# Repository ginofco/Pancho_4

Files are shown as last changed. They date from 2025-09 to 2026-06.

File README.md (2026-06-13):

# Projeto Pancho_4






## 📋 Descrição do Projeto

Protótipo de robô controlado remotamente via rádio utilizando módulos transceptores NRF24L01, desenvolvido para participação em eventos de cultura maker, por exemplo Arduino Day. O projeto inclui um chassis com ponte H e dois motores DC com rodas para movimento, com possibilidade de expansão para um braço robótico.

## ✨ Funcionalidades

- Controle remoto via rádio com módulos NRF24L01
- Chassis personalizado impresso em 3D
- Controle de motores DC com ponte H
- Design modular para futuras expansões (braço robótico)

## 🛠️ Tecnologias e Componentes

- **Microcontroladores:** Arduino Uno R3
- **Comunicação:** Módulos NRF24L01
- **Motores:** 2x Motores DC com caixa de redução, servomotores
- **Driver de Motor:** Ponte H L298N ou similar
- **Power:** Bateria LiPo 7.4V ou baterias de litio
- **Produção:** Impressora 3D Ender-3 Pro
- **Design:** FreeCAD, TinkerCAD

## 📁 Estrutura do Projeto

```
Arduino_Day_2026_Robo/
├── 1_Documentacao/          # Documentação, datasheets e referências
├── 2_Design/                # Arquivos de design 3D (FreeCAD e STLs)
├── 3_Firmware/              # Códigos Arduino para todos os dispositivos
├── 4_Hardware/              # Esquemas elétricos e designs de PCB
└── 5_TestesEvidencias/      # Registros de testes, fotos e vídeos
```

## 🚀 Como Usar

### Pré-requisitos

- IDE Arduino
- Biblioteca RF24 (para comunicação NRF24L01)
- FreeCAD (para visualização e edição de modelos)

### Instalação

1. Clone este repositório:
```bash
git clone https://github.com/[seu-usuario]/ArduinoDay2026-RoboRadio.git
```

2. Instale as bibliotecas necessárias na IDE Arduino:
   - RF24 by TMRh20
   - Outras bibliotecas listadas em `3_Firmware/Bibliotecas/`

3. Abra o sketch desejado na pasta `3_Firmware/`

### Upload para o Arduino

1. Conecte o Arduino ao computador
2. Selecione a placa e porta corretas na IDE Arduino
3. Compile e faça upload do código

## 🎮 Como Controlar

[Descreva aqui como operar o robô quando estiver pronto]

## 📸 Fotos do Projeto

*(Adicione fotos do progresso aqui)*

## 📝 Registro de Desenvolvimento

- **Agosto 2025**: Início do projeto, definição de escopo e estrutura
- **Setembro 2025**: Desenvolvimento do chassis e comunicação básica
- **[Adicione novas etapas conforme o progresso]**

## 👥 Autor

- **Gino** - Maker e entusiasta de robótica - [Comunidade Maker RJ]

## 🙌 Agradecimentos

- Comunidade Maker do Rio de Janeiro
- Fabricantes dos componentes e bibliotecas utilizadas
- Organizadores do Arduino Day 2026
- FabLab do PoloMaker (Rio de Janeiro)

## 📄 Licença

Este projeto está sob a licença MIT. Veja o arquivo [LICENSE](LICENSE) para detalhes.

---

**Nota:** Este projeto está em desenvolvimento. Atualizações regulares serão feitas conforme o progresso.

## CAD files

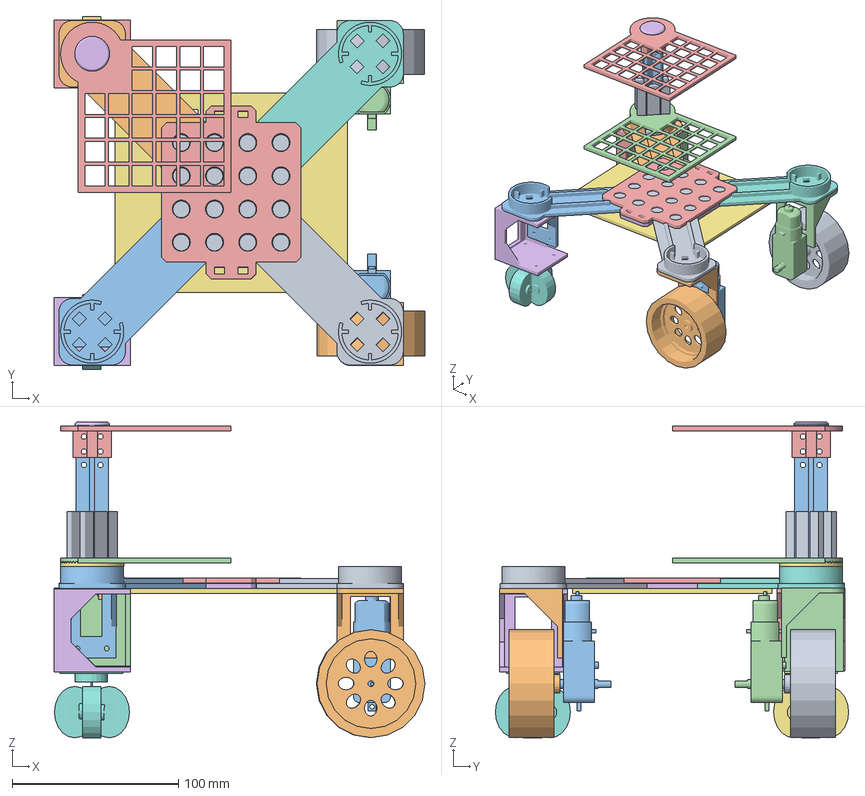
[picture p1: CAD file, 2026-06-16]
2_Design/21_FreeCAD/P4.FCStd
223.3 x 212.7 x 190.0 mm
Core1
Radial_Arm
P3_Suporte_Motor001 (Solid)
Suporte_Motor
Suporte_RodaBoba
Core2
Suporte_Coluna_1
Suporte_Coluna_2
Suporte_Coluna_3
Suporte_Coluna_4
Coluna
Prateleira
Elo_de_Coluna
Topo_Coluna
Javier_aluno
P4_RadialArm_TKCAD_1
P4_RadialArm_TKCAD_2
P4_SuporteMotor_TKCAD
P4_RadialArm_TKCAD_3
P3_Suporte_RodaBoba_TKCAD
P4_Core2_TKCAD
P4_SuporteRodaBoba_TKCAD
P3_RodaBoba_TKCAD_1
P3_RodaBoba_TKCAD_2
P3_RodaGrande_TKCAD_1
P3_RodaGrande_TKCAD_2
P3_Motor_TKCAD_1
P3_Motor_TKCAD_2
P4-Prateleira

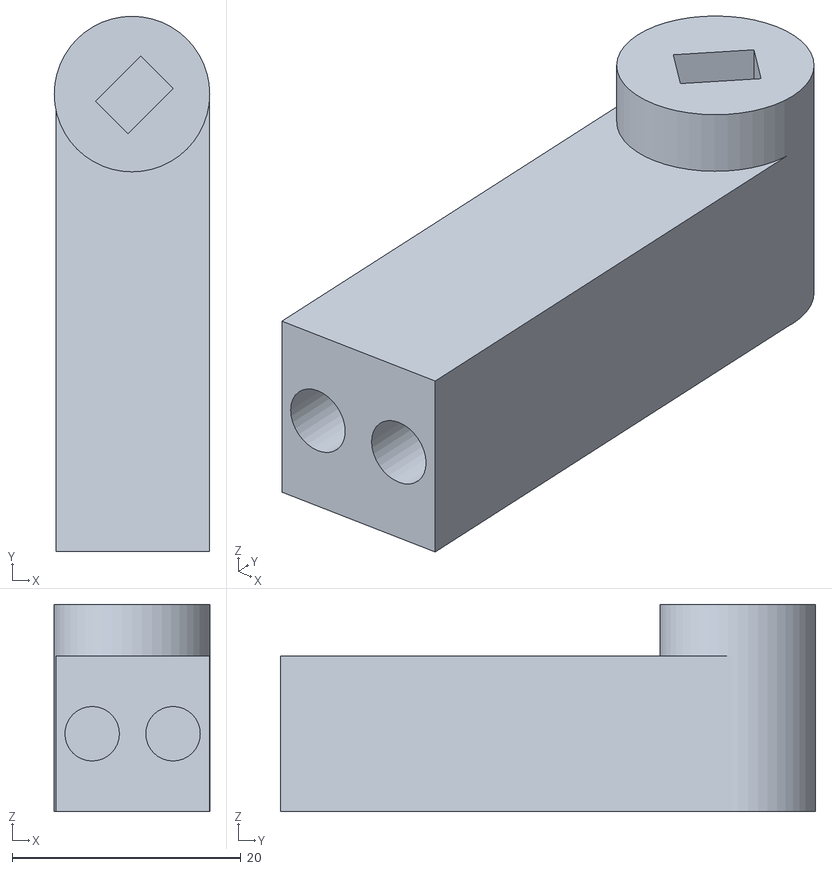
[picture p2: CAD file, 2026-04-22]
2_Design/22_TinkerCAD/P4_Braco-v2.stl
13.6 x 46.8 x 18.1

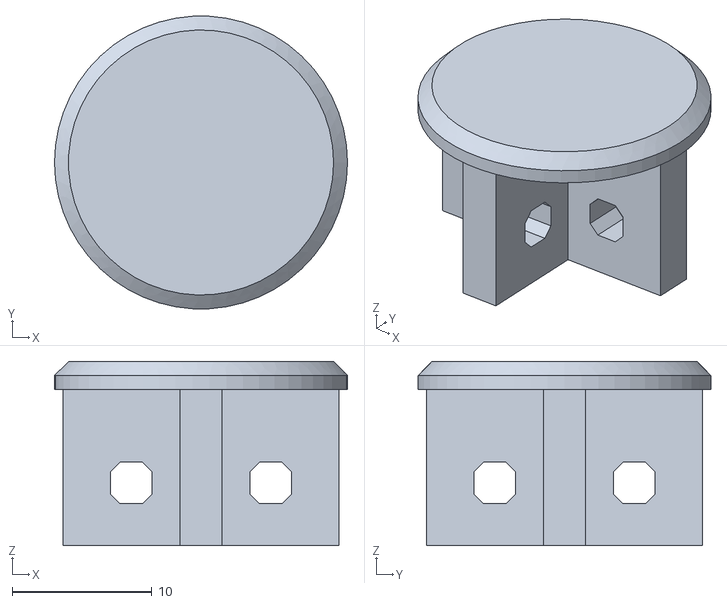
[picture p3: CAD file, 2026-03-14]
2_Design/21_FreeCAD/P4-Topo_Coluna.stl
21.0 x 21.0 x 13.2

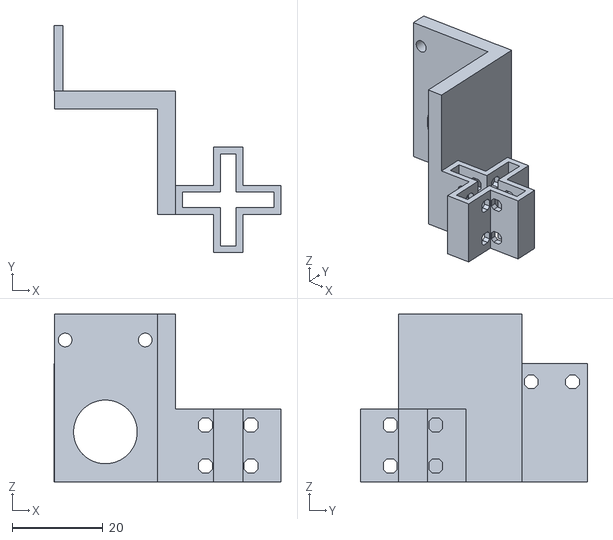
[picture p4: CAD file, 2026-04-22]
2_Design/22_TinkerCAD/P4_SuporteBraco-v2.stl
49.9 x 50.0 x 36.9

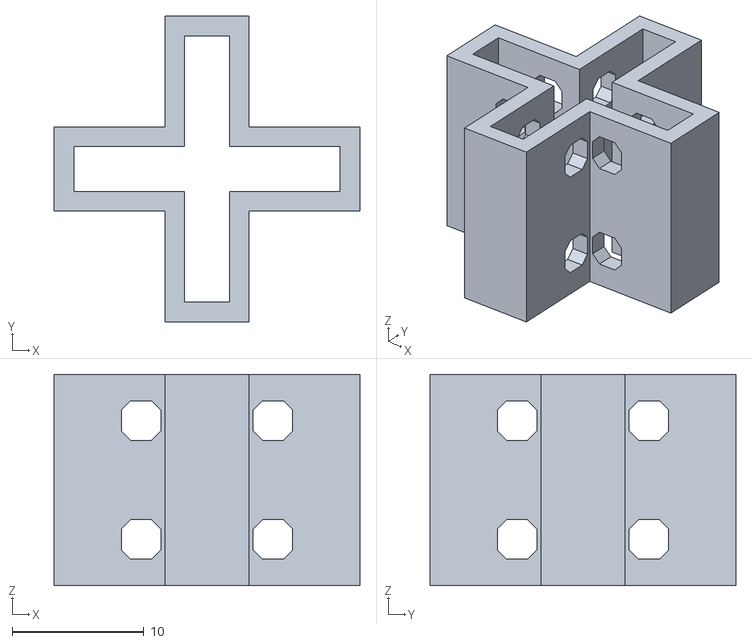
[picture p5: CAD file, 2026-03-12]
2_Design/21_FreeCAD/P4-Elo_de_Coluna.stl
23.2 x 23.2 x 16.0

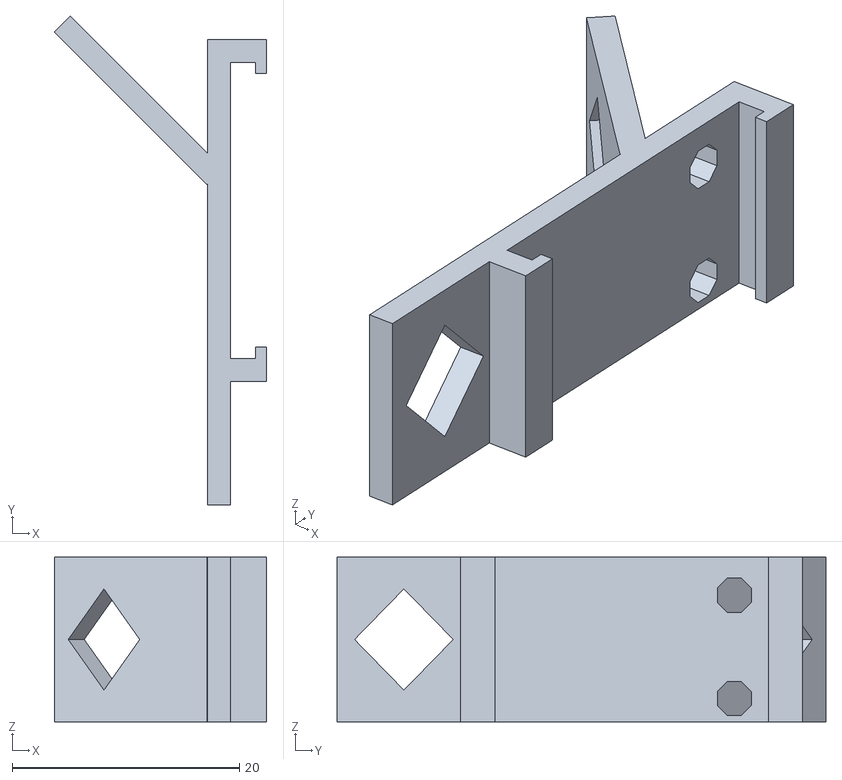
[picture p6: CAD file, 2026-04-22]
2_Design/22_TinkerCAD/P4_SuporteStopBraco-v2.stl
18.7 x 43.1 x 14.5

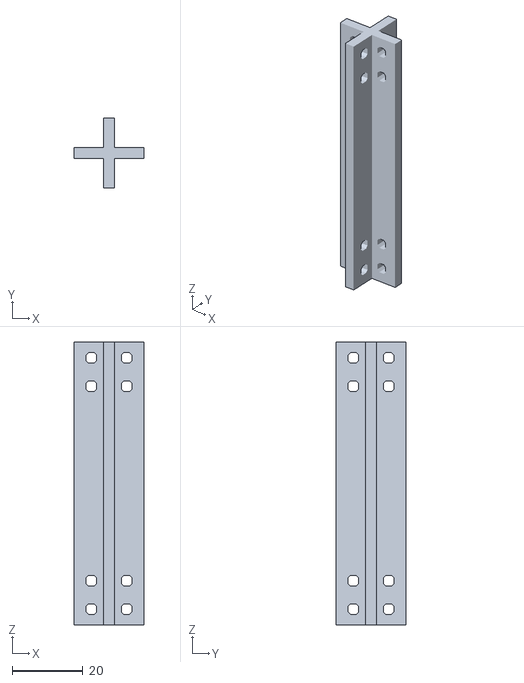
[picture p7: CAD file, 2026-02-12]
2_Design/21_FreeCAD/P4-Coluna.stl
19.8 x 19.8 x 80.0

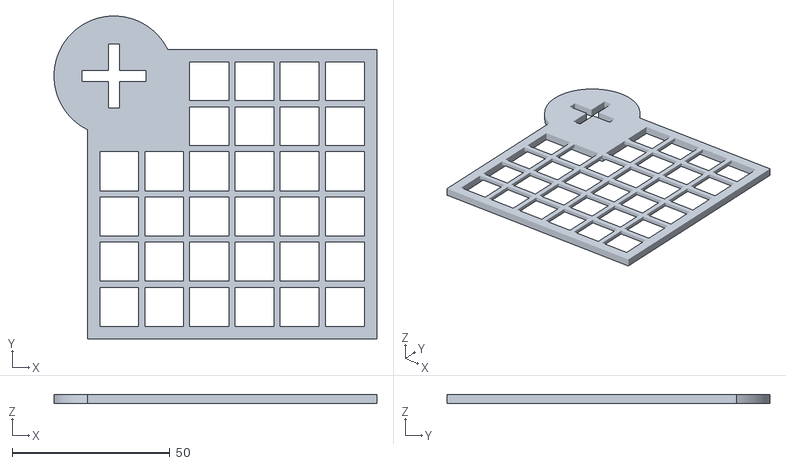
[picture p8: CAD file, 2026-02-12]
2_Design/21_FreeCAD/P4-Prateleira.stl
102.4 x 102.4 x 3.00

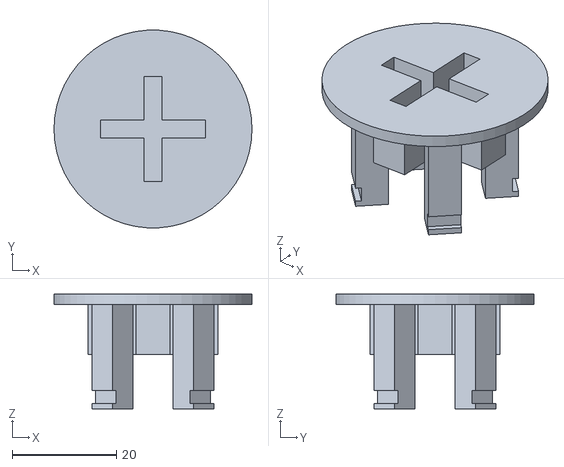
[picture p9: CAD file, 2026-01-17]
2_Design/21_FreeCAD/P4-Suporte_Coluna_4.stl
38.0 x 37.9 x 22.0

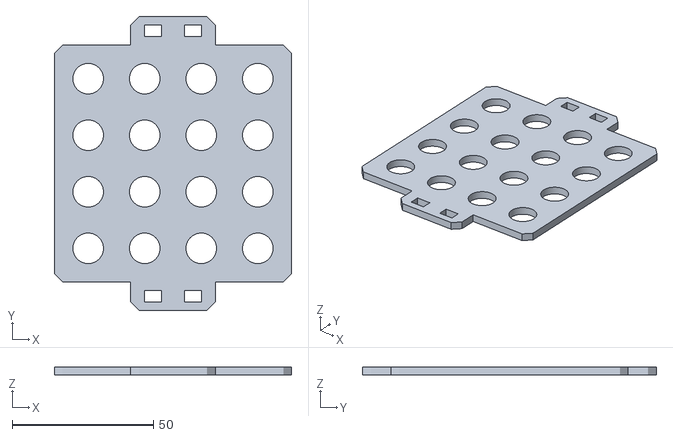
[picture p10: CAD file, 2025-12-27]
2_Design/21_FreeCAD/P4-Core2.stl
84.0 x 104.0 x 3.00

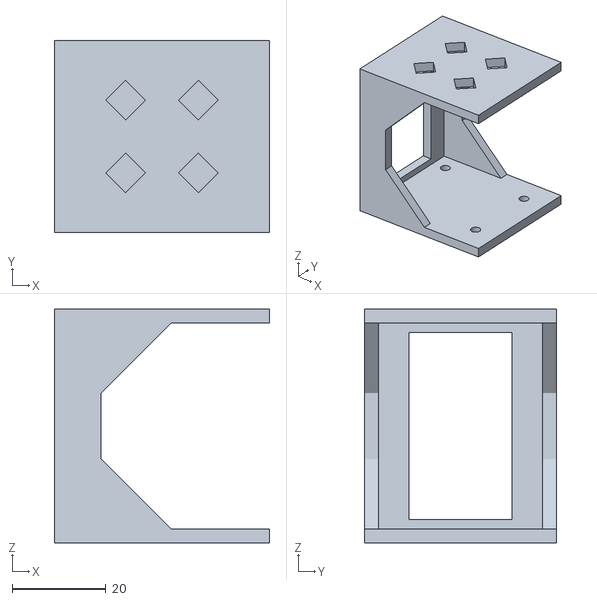
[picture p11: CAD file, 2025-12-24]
2_Design/21_FreeCAD/P4-Suporte_RodaBoba.stl
46.0 x 41.0 x 50.0

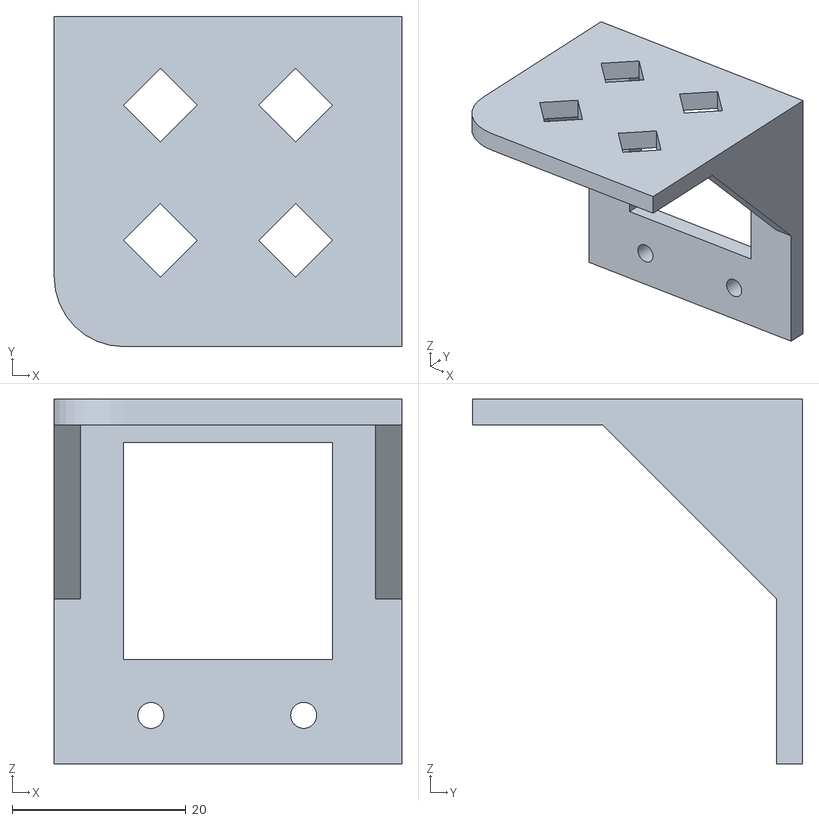
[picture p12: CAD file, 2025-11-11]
2_Design/21_FreeCAD/P4-Suporte_Motor.stl
40.0 x 38.0 x 42.0

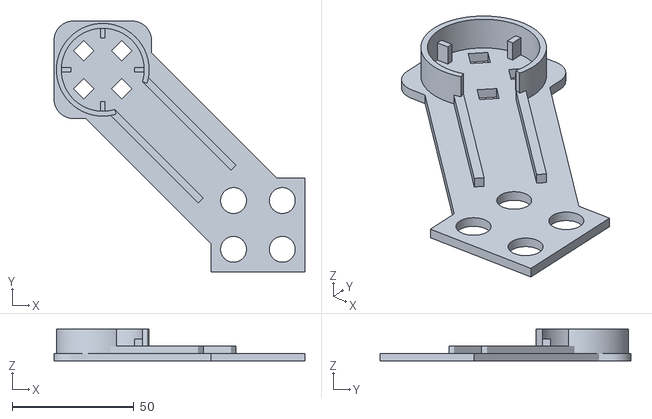
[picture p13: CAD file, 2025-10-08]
2_Design/21_FreeCAD/P4-Radial_Arm.stl
102.9 x 102.9 x 13.0

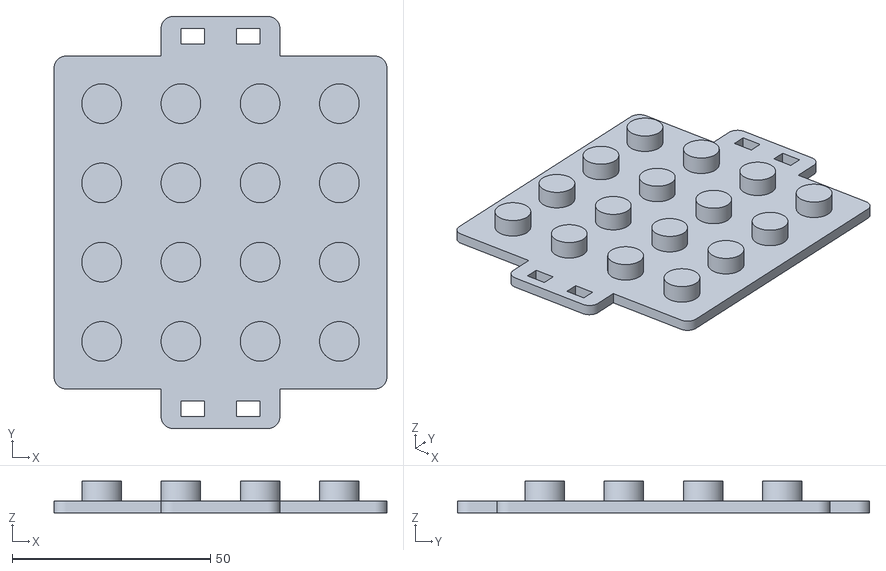
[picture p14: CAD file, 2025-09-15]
2_Design/21_FreeCAD/P4-Core1.stl
84.0 x 104.0 x 8.00

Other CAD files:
2_Design/22_TinkerCAD/P4_Braco.stl
2_Design/22_TinkerCAD/P4_SuporteStopBraco.stl
2_Design/22_TinkerCAD/P4_SuporteBraco.stl

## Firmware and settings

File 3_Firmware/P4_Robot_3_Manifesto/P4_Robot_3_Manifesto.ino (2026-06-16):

// Pancho 4: robot radiocontrolado
// Codigo do Robot - Módulo "Manifesto"
// I2C Slave
// https://www.arduino.cc/en/Tutorial/Tone

#define SLAVE_ADDRESS 0x08
#include <Wire.h>
#include "pitches.h"
#define LEDBLUE 8
#define dirFrente 5
#define dirTras 3
#define esqFrente 9
#define esqTras 6

int volante;
int marcha_frente;
int marcha_tras;
int velocidade=200;
int Motor_L;
int Motor_R;

// notes in the melody:
int melody[] = {
  NOTE_C4, NOTE_G3, NOTE_G3, NOTE_A3, NOTE_G3, 0, NOTE_B3, NOTE_C4
};
// note durations: 4 = quarter note, 8 = eighth note, etc.:
int noteDurations[] = {
  4, 8, 8, 4, 4, 4, 4, 4
};

struct DataPackage {
  int buzina;
  int Motor_L_val;
  int Motor_R_val;
} receivedData;
const int PACKAGE_SIZE = sizeof(DataPackage);

void setup() {
  Serial.begin(57600);
  Serial.println("Pancho 4 - Manifesto: ativado.");

  Wire.begin(SLAVE_ADDRESS);    // join i2c bus with address #8
  //Wire.onReceive(receiveEvent);
  Wire.onReceive(receiveData);
  
  pinMode(esqFrente, OUTPUT);
  pinMode(esqTras, OUTPUT);
  pinMode(dirTras, OUTPUT);
  pinMode(dirFrente, OUTPUT);
  pinMode(LEDBLUE, OUTPUT);
}

byte c=0;
//void receiveEvent(int howMany) {
//   c = Wire.read();
//}

// Função chamada quando dados são recebidos do mestre
void receiveData(int byteCount) {
  if(byteCount == PACKAGE_SIZE) {
    uint8_t *dataPtr = (uint8_t*)&receivedData;
    for(int i = 0; i < PACKAGE_SIZE && Wire.available(); i++) {
      dataPtr[i] = Wire.read();
    }
    // Processar dados recebidos
    processReceivedData();
  } else {
    Serial.print("Tamanho inesperado: ");
    Serial.println(byteCount);
  }
}

void processReceivedData() {
  //Serial.println("\n=== Dados Recebidos ===");
  Serial.print("Modulo Manifesto. Mensagem: velocidade: ");
  Serial.print(receivedData.Motor_L_val);
  Serial.print(" - controle_motores: ");
  Serial.print(receivedData.Motor_R_val);
  Serial.print(" - buzina: ");
  Serial.println(receivedData.buzina);
}


int  velocidade_L;
int  velocidade_R;
void loop() {
  
   Motor_L = receivedData.Motor_L_val;
   Motor_R = receivedData.Motor_R_val;

   if (( Motor_L == 127 ) && ( Motor_R == 127 )) apaga_todos();

   if (( Motor_L <= 127 ) && ( Motor_R <= 127 )) {
     velocidade_L = 200 * ( 127 - Motor_L ) / 127;
     velocidade_R = 200 * ( 127 - Motor_R ) / 127;
     move_p_frente(velocidade_L, velocidade_R);
   }
   if (( Motor_L > 127 ) && ( Motor_R > 127 )) {
     velocidade_L = 200 * ( Motor_L - 127 ) / 127;
     velocidade_R = 200 * ( Motor_R - 127 ) / 127;
     move_p_tras(velocidade_L, velocidade_R);
   }

   /*
   switch(c) {
    case 0:
      apaga_todos();
      break;
    case 1:
      move_p_frente(velocidade);
      break;
    case 2:
      move_p_esquerda_frente(velocidade);
      break;
    case 3:
      move_p_direita_frente(velocidade);
      break;
    case 4:
      move_p_tras(velocidade);
      break;
    case 5:
      move_p_esquerda_tras(velocidade);
      break;
    case 6:
      move_p_direita_tras(velocidade);
      break;
    case 8:
      //play_song();
      acende_blue();
      break;
    case 9:
      //play_song();
      apaga_blue();
      break;
  } 
  */
  // delay(500);
}

void play_song() {
  for (int thisNote = 0; thisNote < 8; thisNote++) {
    // to calculate the note duration, take one second divided by the note type.
    //e.g. quarter note = 1000 / 4, eighth note = 1000/8, etc.
    int noteDuration = 1000 / noteDurations[thisNote];
    tone(8, melody[thisNote], noteDuration);
    // to distinguish the notes, set a minimum time between them.
    // the note's duration + 30% seems to work well:
    int pauseBetweenNotes = noteDuration * 1.30;
    delay(pauseBetweenNotes);
    // stop the tone playing:
    noTone(8);
  }
}

void move_p_frente(int velocidade_L, int velocidade_R) {
  acende_0(velocidade_L);
  apaga_1();
  acende_2(velocidade_R);
  apaga_3();
}
void move_p_tras(int velocidade_L, int velocidade_R) {
  apaga_0();
  acende_1(velocidade_L);  
  apaga_2();
  acende_3(velocidade_L);
}
void move_p_esquerda_frente(int velocidade) {
  acende_0(velocidade);
  apaga_1();
  apaga_2();
  apaga_3();
}
void move_p_direita_frente(int velocidade) {
  apaga_0();
  apaga_1();
  acende_2(velocidade);
  apaga_3();
}
void move_p_esquerda_tras(int velocidade) {
  apaga_0();
  apaga_1();
  apaga_2();
  acende_3(velocidade);
}
void move_p_direita_tras(int velocidade) {
  apaga_0();
  acende_1(velocidade);
  apaga_2();
  apaga_3();
}
void apaga_todos() {
  apaga_0();
  apaga_1();  
  apaga_2();
  apaga_3();
}

void acende_0(int velocidade) {
  analogWrite(esqFrente, velocidade);
}
void acende_1(int velocidade) {
  analogWrite(esqTras, velocidade);
}
void acende_2(int velocidade) {
  analogWrite(dirTras, velocidade);
}
void acende_3(int velocidade) {
  analogWrite(dirFrente, velocidade);
}

void apaga_0() {
  digitalWrite(esqFrente, LOW);
}
void apaga_1() {
  digitalWrite(esqTras, LOW);
}
void apaga_2() {
  digitalWrite(dirTras, LOW);
}
void apaga_3() {
  digitalWrite(dirFrente, LOW);
}

void acende_blue() {
  digitalWrite(LEDBLUE, HIGH);
}
void apaga_blue() {
  digitalWrite(LEDBLUE, LOW);
}

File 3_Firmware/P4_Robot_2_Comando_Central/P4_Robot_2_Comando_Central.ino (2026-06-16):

// Pancho 4: robot radiocontrolado
// Codigo do Robot - Módulo "Controle Central"
// I2C Master

#include <Wire.h>  // I2C
#define SLAVE_ADDRESS_7 0x07  // Comms_RRF
#define SLAVE_ADDRESS_8 0x08  // Manifesto

byte state = 0;

struct DataPackage {
  int buzina;
  int Motor_L_val;
  int Motor_R_val;
} dataToSend_Manifesto;
const int PACKAGE_SIZE = sizeof(DataPackage);

struct NewDataPackage {
  boolean ps2_PSB_SELECT;  // buttons pressed, released or changed state
  boolean ps2_PSB_START;
  boolean ps2_PSB_PAD_UP;
  boolean ps2_PSB_PAD_RIGHT;
  boolean ps2_PSB_PAD_DOWN;
  boolean ps2_PSB_PAD_LEFT;
  boolean ps2_PSB_L2;
  boolean ps2_PSB_R2;
  boolean ps2_PSB_L1;
  boolean ps2_PSB_R1;
  boolean ps2_PSB_GREEN;
  boolean ps2_PSB_RED;
  boolean ps2_PSB_BLUE;
  boolean ps2_PSB_PINK;
  byte    ps2_PSS_RX;  // "Sticks" values
  byte    ps2_PSS_RY;
  byte    ps2_PSS_LX;
  byte    ps2_PSS_LY;
} newReceivedData;

const int NEW_PACKAGE_SIZE = sizeof(NewDataPackage);

void setup() {
  Serial.begin(57600);
  Wire.begin(); // join i2c bus (address optional for master)
  
  iniciaEstrutura();
  
  Serial.println("Pancho 4 - Controle Central: ativado.");
  dataToSend_Manifesto.buzina = 0;
  dataToSend_Manifesto.Motor_L_val = 127;
  dataToSend_Manifesto.Motor_R_val = 127;
}

void loop() {
    //Serial.print("Master. Recebendo dados: ");   
    // Solicita dados do slave
    requestDataFromSlave();
    
    //displayData();
    
    dataToSend_Manifesto.buzina      = newReceivedData.ps2_PSB_BLUE;
    dataToSend_Manifesto.Motor_L_val = newReceivedData.ps2_PSS_RY;
    dataToSend_Manifesto.Motor_R_val = newReceivedData.ps2_PSS_LY;
  
    Serial.print("Master. Enviando dados: ");    
    Serial.print(" - buzina: ");
    Serial.print(dataToSend_Manifesto.buzina);
    Serial.print(" - Motor L: ");
    Serial.print(dataToSend_Manifesto.Motor_L_val);
    Serial.print(" - Motor R: ");
    Serial.print(dataToSend_Manifesto.Motor_R_val);
    Serial.println(" ");

    transmitData_Manifesto();

    //dataToSend_Manifesto.buzina++;
    //if (dataToSend_Manifesto.buzina>1) dataToSend_Manifesto.buzina=0;
    //dataToSend_Manifesto.controle_motores++;
    //if (dataToSend_Manifesto.controle_motores>9) dataToSend_Manifesto.controle_motores=0;

    // Aguarda um tempo antes da próxima leitura
    delay(50);
}

void requestDataFromSlave() {
  // Solicita o número de bytes igual ao tamanho da estrutura
  Wire.requestFrom(SLAVE_ADDRESS_7, sizeof(NewDataPackage));
  
  // Verifica se recebeu a quantidade correta de bytes
  uint8_t bytesReceived = 0;
  if(Wire.available() >= sizeof(NewDataPackage)) {
    
    // Lê os bytes diretamente para a estrutura
    for(uint8_t i = 0; i < sizeof(NewDataPackage); i++) {
      ((uint8_t*)&newReceivedData)[i] = Wire.read();
    }
    bytesReceived = sizeof(NewDataPackage);
    
    // Processa os dados recebidos
    //displayReceivedData();
    
  } else {
    Serial.print("Erro: Recebido apenas ");
    Serial.print(Wire.available());
    Serial.print(" de ");
    Serial.print(sizeof(NewDataPackage));
    Serial.println(" bytes esperados");
  }
}

void transmitData_Manifesto() {
  Wire.beginTransmission(SLAVE_ADDRESS_8);
  // Envia byte a byte da estrutura
  uint8_t *dataPtr = (uint8_t*)&dataToSend_Manifesto;
  for(size_t i = 0; i < PACKAGE_SIZE; i++) {
    Wire.write(dataPtr[i]);
  }
  byte error = Wire.endTransmission();
}

void iniciaEstrutura() {
  newReceivedData.ps2_PSB_SELECT    = false;
  newReceivedData.ps2_PSB_START     = false;
  newReceivedData.ps2_PSB_R1        = false;
  newReceivedData.ps2_PSB_R2        = false;
  newReceivedData.ps2_PSB_L1        = false;
  newReceivedData.ps2_PSB_L2        = false;
  newReceivedData.ps2_PSB_PAD_UP    = false;
  newReceivedData.ps2_PSB_PAD_RIGHT = false;
  newReceivedData.ps2_PSB_PAD_DOWN  = false;
  newReceivedData.ps2_PSB_PAD_LEFT  = false;
  newReceivedData.ps2_PSB_GREEN     = false;
  newReceivedData.ps2_PSB_RED       = false;
  newReceivedData.ps2_PSB_BLUE      = false;
  newReceivedData.ps2_PSB_PINK      = false;
  newReceivedData.ps2_PSS_RX        = 128;
  newReceivedData.ps2_PSS_RY        = 128;
  newReceivedData.ps2_PSS_LX        = 128;
  newReceivedData.ps2_PSS_LY        = 128;
}

void displayData() {
    Serial.print("P4_ModuloRRF. - Select: "); Serial.print(newReceivedData.ps2_PSB_SELECT);
    Serial.print(" - Start: ");             Serial.print(newReceivedData.ps2_PSB_START);
    Serial.print(" - R1: ");                Serial.print(newReceivedData.ps2_PSB_R1);
    Serial.print(" - R2: ");                Serial.print(newReceivedData.ps2_PSB_R2);
    Serial.print(" - L1: ");                Serial.print(newReceivedData.ps2_PSB_L1);
    Serial.print(" - L2: ");                Serial.print(newReceivedData.ps2_PSB_L2);
    Serial.print(" - PAD_UP: ");            Serial.print(newReceivedData.ps2_PSB_PAD_UP);
    Serial.print(" - PAD_RIGHT: ");         Serial.print(newReceivedData.ps2_PSB_PAD_RIGHT);
    Serial.print(" - PAD_DOWN: ");          Serial.print(newReceivedData.ps2_PSB_PAD_DOWN);
    Serial.print(" - PAD_LEFT: ");          Serial.print(newReceivedData.ps2_PSB_PAD_LEFT);
    Serial.print(" - GREEN: ");             Serial.print(newReceivedData.ps2_PSB_GREEN);
    Serial.print(" - RED: ");               Serial.print(newReceivedData.ps2_PSB_RED);
    Serial.print(" - BLUE: ");              Serial.print(newReceivedData.ps2_PSB_BLUE);
    Serial.print(" - PINK: ");              Serial.print(newReceivedData.ps2_PSB_PINK);
    Serial.print(" - RX: ");                Serial.print(newReceivedData.ps2_PSS_RX);
    Serial.print(" - RY: ");                Serial.print(newReceivedData.ps2_PSS_RY);
    Serial.print(" - LX: ");                Serial.print(newReceivedData.ps2_PSS_LX);
    Serial.print(" - LY: ");                Serial.print(newReceivedData.ps2_PSS_LY);
    Serial.println(" * ");
}

////////////////////////////////////////////////////////////////////////

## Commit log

2025-09-08 Create README.md
    Copiando o README.md para a raiz. Realizar o apagamento do arquivo copiado de ~/Documentacao
2025-09-15 Lançamento_da_Primeira_Peça
    Agregando o projeto FreeCAD do P4, já com primeira peça, em impressão
    [P4-Core1.stl, P4.FCStd]
2025-09-16 Iniciando a 2a parte (Radial_Arm)
    [P4.FCStd]
2025-09-20 Atualizacoes na peca Radial Arm
    [P4.FCStd]
2025-09-23 Mais uma atualizacao do Radial Arm
    [P4.FCStd]
2025-09-30 Nova atualizacao de 30-09-2025
    [P4.FCStd]
2025-10-08 Melhoria efetiva do Radial_Arm
    [P4-Radial_Arm.stl, P4.FCStd]
2025-10-11 Inclusao do Suporte_Motor de STL para Mesh, posicionamento
    [P4.FCStd]
2025-10-14 Atualização do SuporteMotor
    [P4.FCStd]
2025-10-18 Iniciando 4a peça: Suporte_coluna.
    [P4-Suporte_Motor.stl, P4.FCStd]
2025-10-22 Ajuste no suporte da coluna, inserindo borda semicircular.
    [P4.FCStd]
2025-11-04 Final do suporte de coluna.
    [P4-Suporte_Coluna.stl, P4.FCStd]
2025-11-11 Correções radicais no projeto CAD, mais teste com Arduino e PS2, mais cópias dos programas do P4 para pasta de GitHub.
    [P4-Suporte_Coluna.stl, P4-Suporte_Motor.stl, P4.FCStd]
2025-12-09 Testes e inserção de comandos I2C
2025-12-10 Adaptação do código do Console - Módulo PS2 - para receber estrutura de dados do controle PS2
2025-12-13 Teste bem sucedido de comunicação I2C entre Console-PS2 E Console-RRF
2025-12-16 Teste bem-sucedido de comunicação RF entre console (completo) e primeiro módulo do robô.
2025-12-16 Melhorias no modelo 3d
    [P4.FCStd]
2025-12-18 Refazendo parte do Suporte da Roda Boba
    [P4.FCStd]
2025-12-24 Suporte de roda boba adicionado.
    [P4-Suporte_RodaBoba.stl, P4-Suporte_RodaBoba_.stl, P4-Suporte_RodaBoba_1.stl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]
2025-12-27 Inclusão da parte P4-Core2
    [P4-Core2.stl, P4-Suporte_RodaBoba.stl, P4-Suporte_RodaBoba_.stl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]
2025-12-27 Agregação das partes, com inclusão de motores e de rodas.
    [P4.FCStd]
2025-12-29 Adicionado suporte para coluna
    [P4-Suporte_Coluna_1.stl, P4.FCStd]
2026-01-06 Testes em ideias para Suporte da Coluna.
    [P4.FCStd]
2026-01-07 Início da 3 tentativa para Suporte da Coluna (ou primeira coluna, direto)
    [P4.FCStd]
2026-01-10 Etapa de elaboração do suporte da coluna
    [P4.FCStd]
2026-01-14 Seguindo com a 4a tentativa para Suporte da Coluna.
    [P4.FCStd]
2026-01-17 Peça completada Suporte_Coluna_4.
    [P4-Suporte_Coluna_4.stl, P4.FCStd]
2026-01-25 Coluna com 16 furos.
    descrição
    [P4.FCStd]
2026-01-27 Iniciando Prateleira
    [P4.FCStd]
2026-02-03 Início da Plataforma
    [P4.FCStd]
2026-02-04 Vazando grade na Prateleira, com entrada para coluna
    [P4.FCStd]
2026-02-07 Escavando parte útil da Prateleira
    [P4.FCStd]
2026-02-12 Alterações na Coluna, visando melhor adaptar o conector entre colunas
    [P4-Coluna.stl, P4-Prateleira.stl, P4.FCStd]
2026-03-04 Criando o Elo_de_Coluna
    [P4.FCStd]
2026-03-10 Finalizado elo entre colunas.
    [P4-Suporte_Coluna_1.stl, P4.FCStd]
2026-03-12 Exportando o Elo de Coluna, exibindo o robô.
    [P4-Elo_de_Coluna.stl, P4.FCStd]
2026-03-14 Incluindo a peça Topo_Coluna
    [P4-Topo_Coluna.stl, P4.FCStd]
2026-04-16 Ligação I2C Controle Central ao Manifesto
2026-04-18 Incluindo na pasta modelagens do TinkerCAD
    [P4_Braco.stl, P4_SuporteBraco.stl, P4_SuporteStopBraco.stl]
2026-04-18 Programando Controle Central para enviar estrutura para o Manifesto
2026-04-22 Refazendo todas peças anteriores
    [P4.FCStd, P4_Braco-v2.stl, P4_SuporteBraco-v2.stl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]
2026-04-27 Preparação para Manifesto receber estrutura do Comando Central
2026-04-29 Aumentando a estrutura de dados do Console
2026-05-02 Teste com nova estrutura de dados e controle do PS2
    [P4.FCStd]
2026-05-05 Desenvolvimento e teste da transmissão I2C do Console, estrutura de dados completa
2026-05-09 Consegui transmitir estrutura grande do Console para o Módulo Comunicação RF
2026-05-09 Trabalhando na comunicação Comms RRF vers Controle Central
    [P4.FCStd]
2026-05-12 Preparando Comms_RRF e Comando_Central para transmissão de estrutura completa Slave->Master
2026-06-06 Primeiro teste de recepção de dados no Comando Central - resultado ok
2026-06-13 Preparação para teste do Manifesto usando comando transmitido do Console
2026-06-16 Melhorias na transmissão de dados entre Comando Central e o Manifesto
    [P4.FCStd]
2026-06-23 Investigando falha de comunicação Console-Robot
2026-06-27 Investigando problemas comm RF
    [P4_Console_1_Module_PS2.ino, P4_Console_2_Module_RRF.ino, Teste_Robot_1_Comms_RRF_alternativo.ino]
2026-07-08 Teste com o código do transmissor (teste) instalado no Arduino do console, com hardware novo plugado
2026-07-11 Bom estado de transmissão, usando código no console RF ligeiramente mudado, e receptor de teste
2026-07-11 Transmitindo toda estrutura, porém a informação não está passando pelo I2C no r.Pancho
2026-10-28 Testes de I2C
